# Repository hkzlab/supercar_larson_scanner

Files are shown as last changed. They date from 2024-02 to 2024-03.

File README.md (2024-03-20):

# "Supercar" Larson Scanner

## Introduction

"Supercar" is the (stupid) italian name for the [Knight Rider](https://en.wikipedia.org/wiki/Knight_Rider_(1982_TV_series)) TV series.
In that series, the iconic car KITT sports a red light going back and forth under the hood. That effect is called "[Larson](https://en.wikipedia.org/wiki/Glen_A._Larson) scanner".

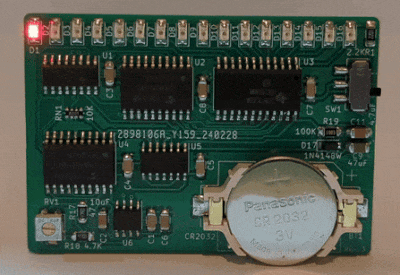
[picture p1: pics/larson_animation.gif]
Rev. 3 Board animation


This board implements a "Larson scanner" with regulable speed using a 555 timer and a few 74' CMOS logic ICs (two latches, a full adder, a demux and a 4x 2-in xor gate).
It's powered by a CR2032 coin cell battery.

The circuit is quite simple to understand and a good exercise on SMD hand-soldering.

### Disclaimer

I take NO responsibility for what happens if you decide to build and use this card. But You're encourauged to take what you deem fit from this, and use it in your projects!

## Verilog simulation

You can find a verilog implementation of the circuit under the `supercar_verilog` directory, complete with a testbench.

## Bill of Materials

Remember to use a CMOS variant of the 555 timer compatible with a low supply voltage, like [this](https://www.mouser.it/ProductDetail/926-LMC555CMX-NOPB).

**TODO**

## Required Fixes

### Rev. 1

* Pin 4 of the RN1 resistor network is unconnected and should be connected to +3.3V. Pin 16 of U1 is a good spot.

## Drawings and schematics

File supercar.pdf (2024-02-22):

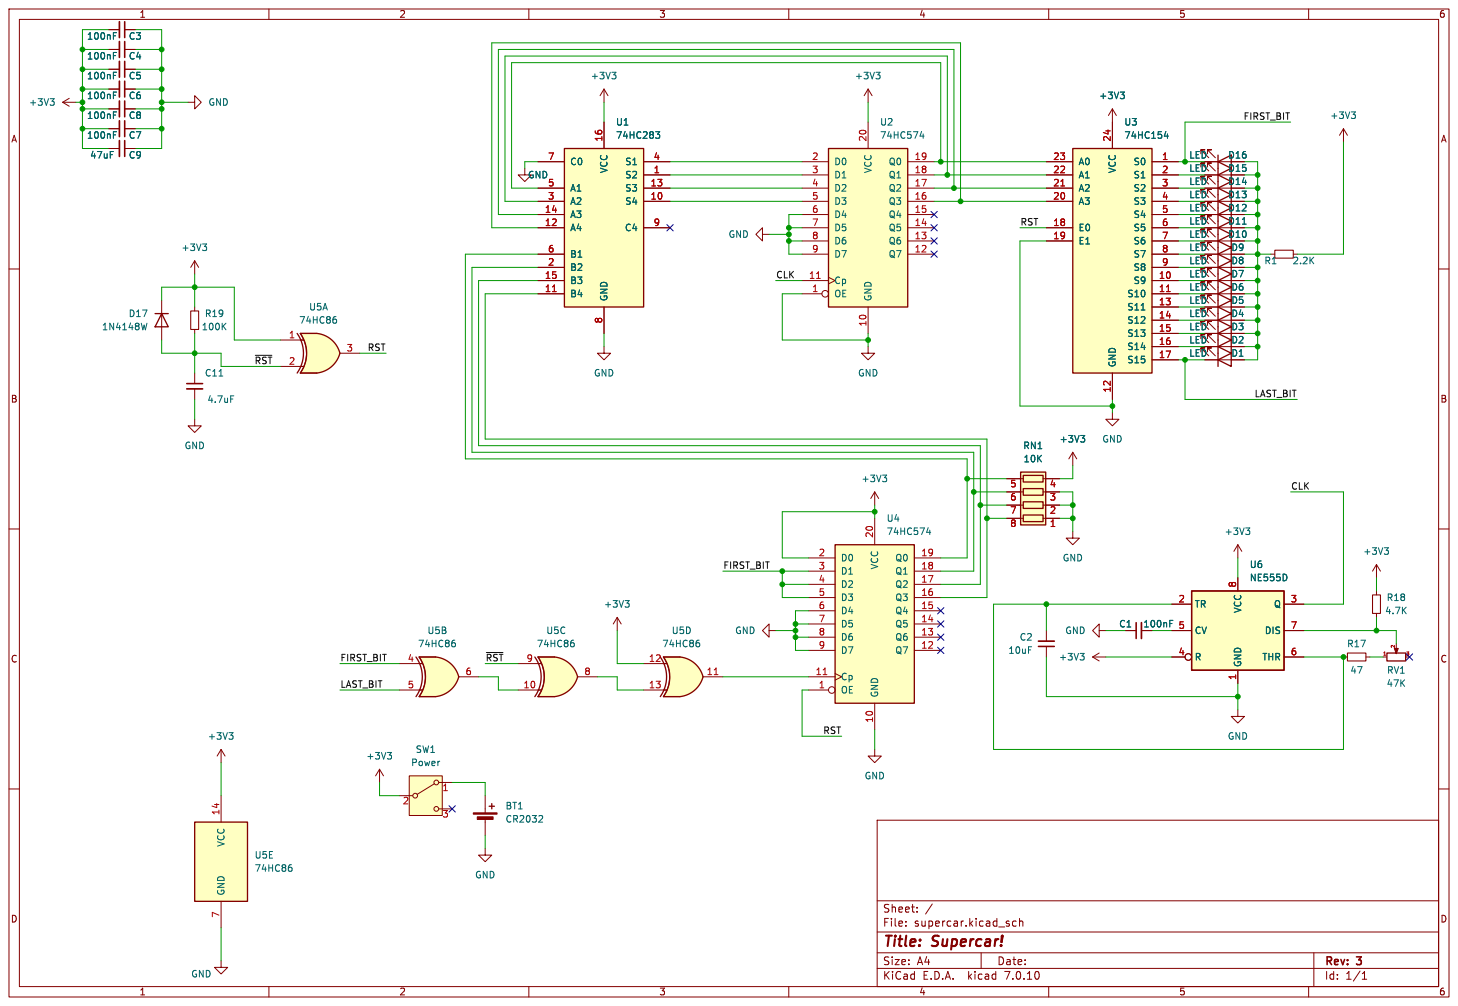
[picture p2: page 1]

Id: 1/1 Title: Supercar! File: supercar.kicad_sch Sheet: /

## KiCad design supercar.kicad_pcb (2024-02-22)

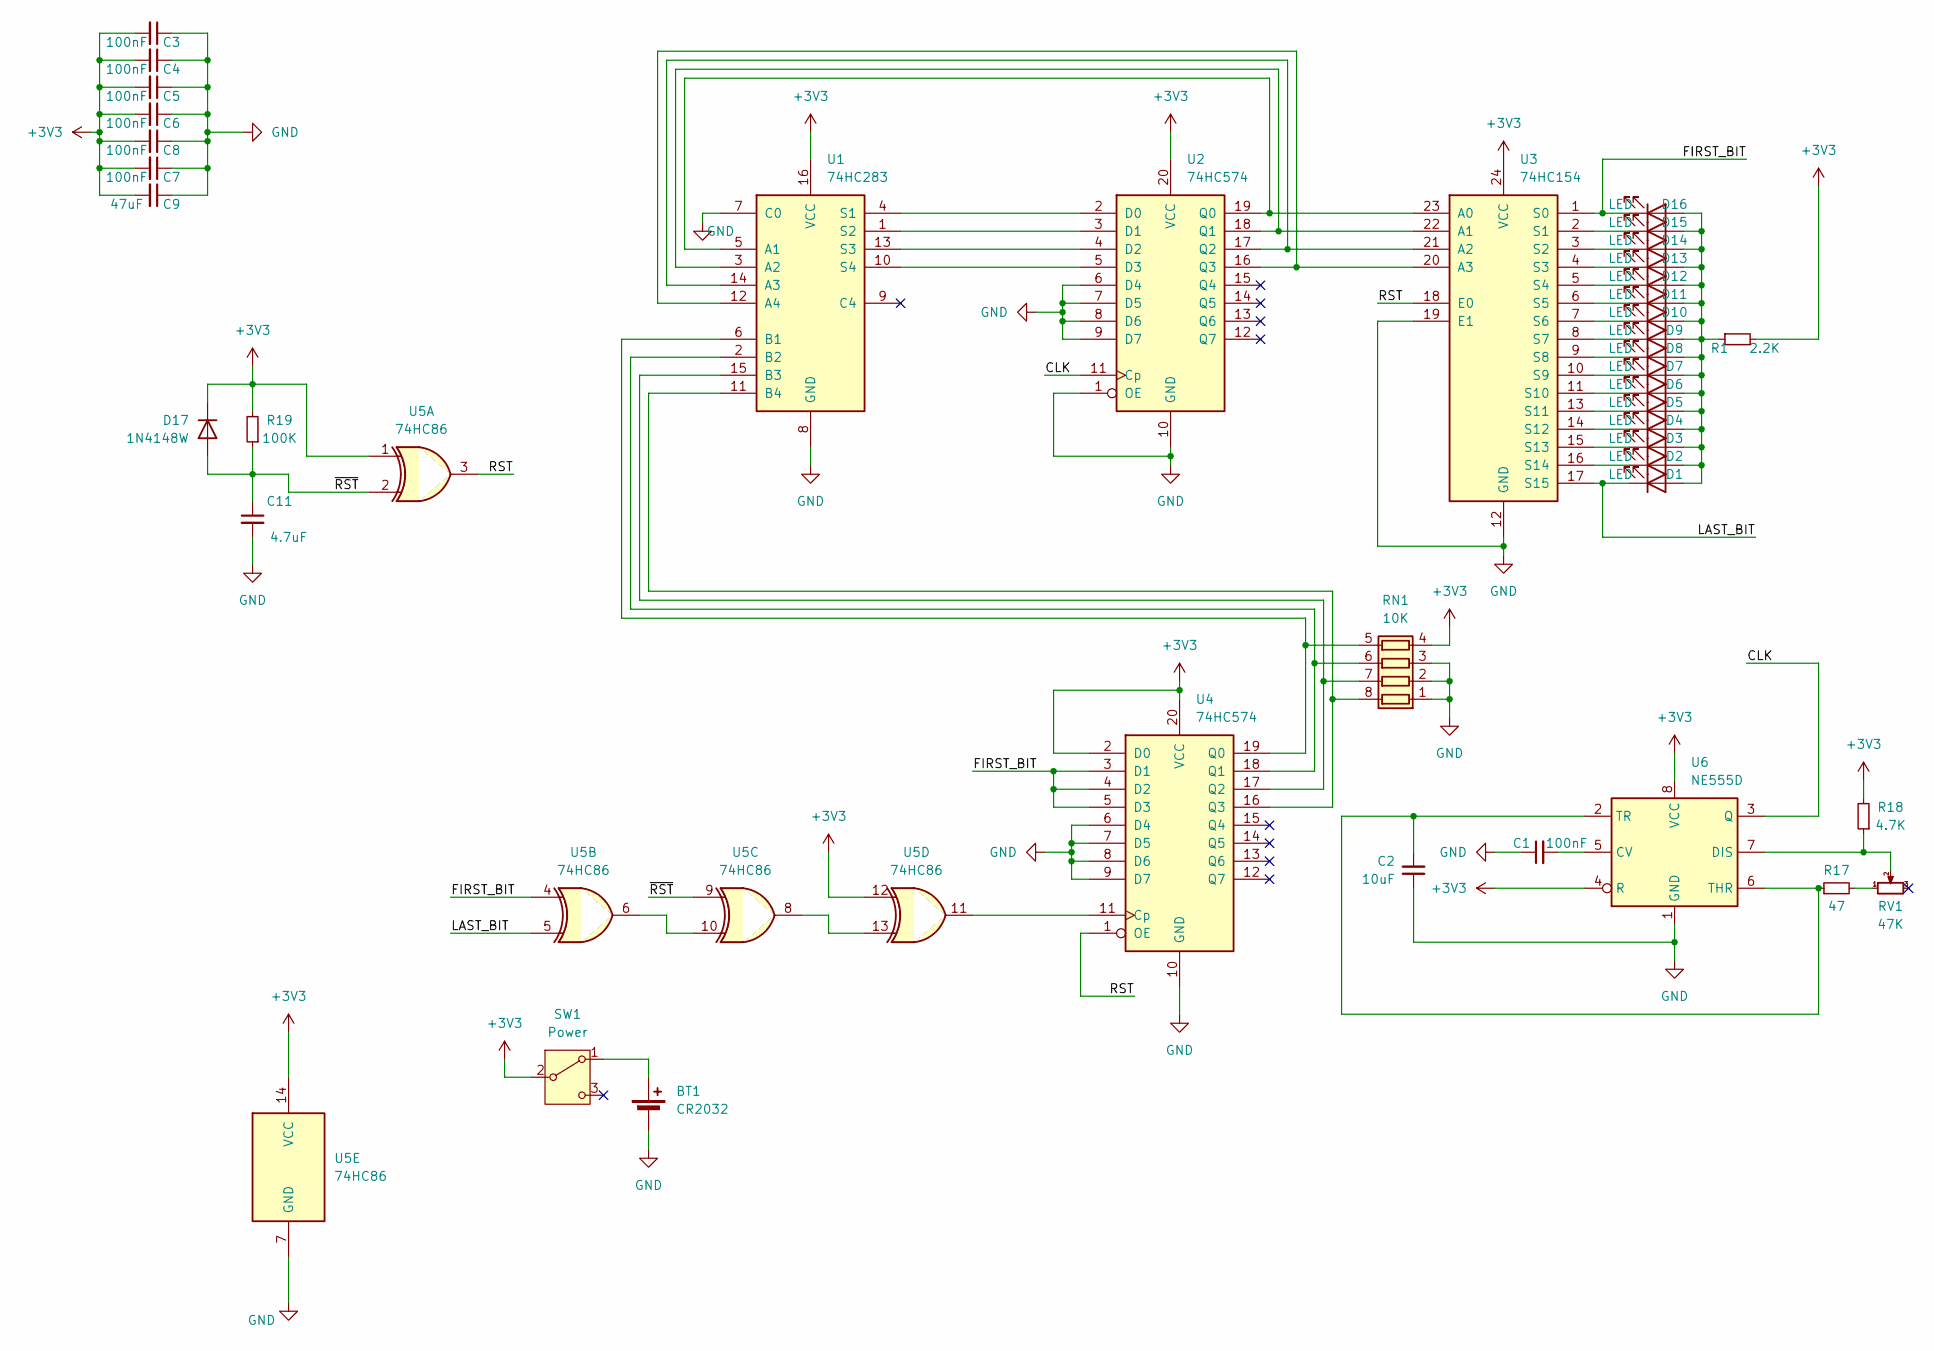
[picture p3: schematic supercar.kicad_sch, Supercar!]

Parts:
BT1: CR2032; BatteryHolder_Keystone_1060_1x2032
C1, C3, C4, C5, C6, C7, C8: 100nF; C_1206_3216Metric_Pad1.33x1.80mm_HandSolder
C2: 10uF; C_1206_3216Metric_Pad1.33x1.80mm_HandSolder
C9: 47uF; C_1206_3216Metric_Pad1.33x1.80mm_HandSolder
C11: 4.7uF; C_1206_3216Metric_Pad1.33x1.80mm_HandSolder
D1, D2, D3, D4, D5, D6, D7, D8, D9, D10, D11, D12, D13, D14, D15, D16: LED; LED_1206_3216Metric_Pad1.42x1.75mm_HandSolder
D17: 1N4148W; D_SOD-123
R1: 2.2K; R_1206_3216Metric_Pad1.30x1.75mm_HandSolder
R17: 47; R_1206_3216Metric_Pad1.30x1.75mm_HandSolder
R18: 4.7K; R_1206_3216Metric_Pad1.30x1.75mm_HandSolder
R19: 100K; R_1206_3216Metric_Pad1.30x1.75mm_HandSolder
RN1: 10K; R_Array_Convex_4x0612
RV1: 47K; Potentiometer_Bourns_3314G_Vertical
SW1: Power; SW_Slide_1P2T_CK_OS102011MS2Q
U1: 74HC283; SOIC-16_3.9x9.9mm_P1.27mm
U2, U4: 74HC574; SOIC-20W_7.5x12.8mm_P1.27mm
U3: 74HC154; SOIC-24W_7.5x15.4mm_P1.27mm
U5: 74HC86; SOIC-14_3.9x8.7mm_P1.27mm
U6: NE555D; SOIC-8_3.9x4.9mm_P1.27mm

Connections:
+3V3: C3.2, C4.2, C5.2, C6.2, C7.2, C8.2, C9.2, D17.1 (K), R1.2, R18.2, R19.2, RN1.4 (R4.1), SW1.2 (B), U1.16 (VCC), U2.20 (VCC), U3.24 (VCC), U4.2 (D0), U4.20 (VCC), U5.1, U5.12, U5.14 (VCC), U6.4 (R), U6.8 (VCC)
/CLK: U2.11 (Cp), U6.3 (Q)
/FIRST_BIT: D16.1 (K), U3.1 (S0), U4.3 (D1), U4.4 (D2), U4.5 (D3), U5.4
/LAST_BIT: D1.1 (K), U3.17 (S15), U5.5
/RST: U3.18 (E0), U4.1 (OE), U5.3
/~RST: C11.1, D17.2 (A), R19.1, U5.2, U5.9
GND: BT1.2 (-), C1.1, C2.1, C3.1, C4.1, C5.1, C6.1, C7.1, C8.1, C9.1, C11.2, RN1.1 (R1.1), RN1.2 (R2.1), RN1.3 (R3.1), U1.7 (C0), U1.8 (GND), U2.1 (OE), U2.6 (D4), U2.7 (D5), U2.8 (D6), U2.9 (D7), U2.10 (GND), U3.12 (GND), U3.19 (E1), U4.6 (D4), U4.7 (D5), U4.8 (D6), U4.9 (D7), U4.10 (GND), U5.7 (GND), U6.1 (GND)
unnamed: BT1.1 (+), SW1.1 (A)
unnamed: D1.2 (A), D2.2 (A), D3.2 (A), D4.2 (A), D5.2 (A), D6.2 (A), D7.2 (A), D8.2 (A), D9.2 (A), D10.2 (A), D11.2 (A), D12.2 (A), D13.2 (A), D14.2 (A), D15.2 (A), D16.2 (A), R1.1
unnamed: D2.1 (K), U3.16 (S14)
unnamed: D3.1 (K), U3.15 (S13)
unnamed: D4.1 (K), U3.14 (S12)
unnamed: D5.1 (K), U3.13 (S11)
unnamed: D6.1 (K), U3.11 (S10)
unnamed: D7.1 (K), U3.10 (S9)
unnamed: D8.1 (K), U3.9 (S8)
unnamed: D9.1 (K), U3.8 (S7)
unnamed: D10.1 (K), U3.7 (S6)
unnamed: D11.1 (K), U3.6 (S5)
unnamed: D12.1 (K), U3.5 (S4)
unnamed: D13.1 (K), U3.4 (S3)
unnamed: D14.1 (K), U3.3 (S2)
unnamed: D15.1 (K), U3.2 (S1)
unnamed: R17.2, RV1.1
unnamed: RN1.8 (R1.2), U1.11 (B4), U4.16 (Q3)
unnamed: RN1.7 (R2.2), U1.15 (B3), U4.17 (Q2)
unnamed: RN1.6 (R3.2), U1.2 (B2), U4.18 (Q1)
unnamed: RN1.5 (R4.2), U1.6 (B1), U4.19 (Q0)
unnamed: U1.5 (A1), U2.19 (Q0), U3.23 (A0)
unnamed: U1.3 (A2), U2.18 (Q1), U3.22 (A1)
unnamed: U1.14 (A3), U2.17 (Q2), U3.21 (A2)
unnamed: U1.12 (A4), U2.16 (Q3), U3.20 (A3)
unnamed: U1.4 (S1), U2.2 (D0)
unnamed: U1.1 (S2), U2.3 (D1)
unnamed: U1.13 (S3), U2.4 (D2)
unnamed: U1.10 (S4), U2.5 (D3)
unnamed: U4.11 (Cp), U5.11
unnamed: U5.6, U5.10
unnamed: U5.8, U5.13
unnamed: C1.2, U6.5 (CV)
unnamed: R18.1, RV1.2, U6.7 (DIS)
unnamed: C2.2, R17.1, U6.2 (TR), U6.6 (THR)

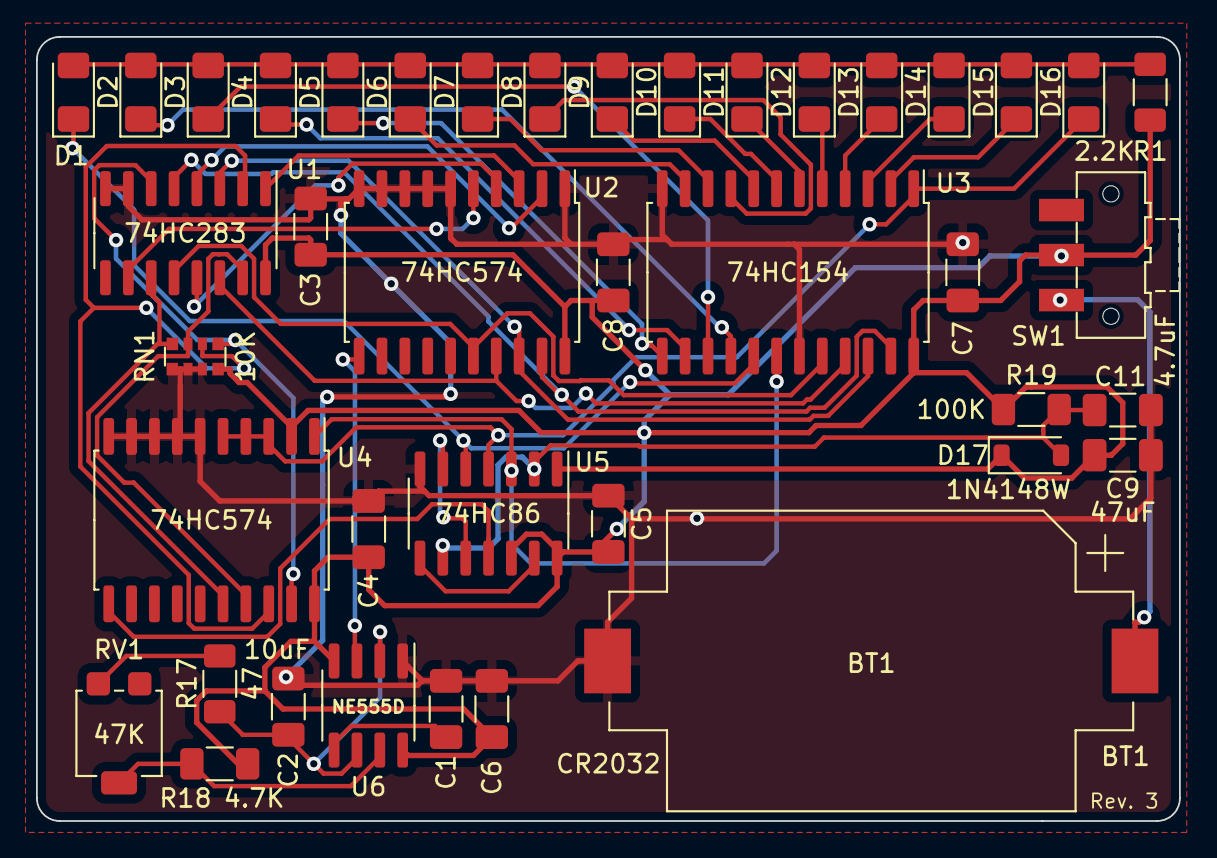
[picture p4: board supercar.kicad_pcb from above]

Board: 2 copper layers, 63.5 x 43.6 mm, 41 parts (0 on the bottom side), 42 nets.

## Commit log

2024-01-07 Assigned footprints
    [supercar.kicad_pcb, supercar.kicad_sch]
2024-01-07 add pcb
    [supercar.kicad_pcb, supercar.kicad_sch]
2024-01-08 Carry bit must be set to 0
    [supercar.kicad_pcb, supercar.kicad_sch]
2024-01-24 Fix led orientation and connection
    [supercar.kicad_pcb, supercar.kicad_sch]
2024-01-25 Update the PCB to include a reset circuit
    [supercar.kicad_pcb, supercar.kicad_sch]
2024-01-25 Reorganize silkscreen a bit
    [supercar.kicad_pcb, supercar.kicad_sch]
2024-01-26 Update schematic and PCB
    [supercar.kicad_pcb, supercar.kicad_sch]
2024-01-26 Slight change to PCB
    [supercar.kicad_pcb]
2024-01-29 Reduce IC count and reroute the board
    [supercar.kicad_pcb, supercar.kicad_sch]
2024-02-04 Update schematics
    [supercar.kicad_pcb, supercar.kicad_sch]
2024-02-04 Use a single resistor, reduce the size of the PCB
    [supercar.kicad_pcb, supercar.kicad_sch]
2024-02-15 Fix cap position in rev3
    [supercar.kicad_pcb, supercar.kicad_sch]
2024-02-16 Reroute rev_3
    [supercar.kicad_pcb, supercar.kicad_sch]
2024-02-16 Update the schematic
2024-02-17 add 47uf cap as buffer to battery
    [supercar.kicad_pcb, supercar.kicad_sch]
2024-02-17 Resistor led now 2.2K
    [supercar.kicad_pcb, supercar.kicad_sch]
2024-02-22 Change reset circuit to not turn on leds
    [supercar.kicad_pcb, supercar.kicad_sch]
2024-02-22 Small change in component value
    [supercar.kicad_pcb, supercar.kicad_sch]
2024-02-22 Feed the reset circuit on the delay line of the adder clock
    [supercar.kicad_pcb, supercar.kicad_sch]
2024-02-22 Further changes to the board, changed the switch
    [supercar.kicad_pcb]
2024-02-27 Fix schematics
    [supercar.kicad_sch]
